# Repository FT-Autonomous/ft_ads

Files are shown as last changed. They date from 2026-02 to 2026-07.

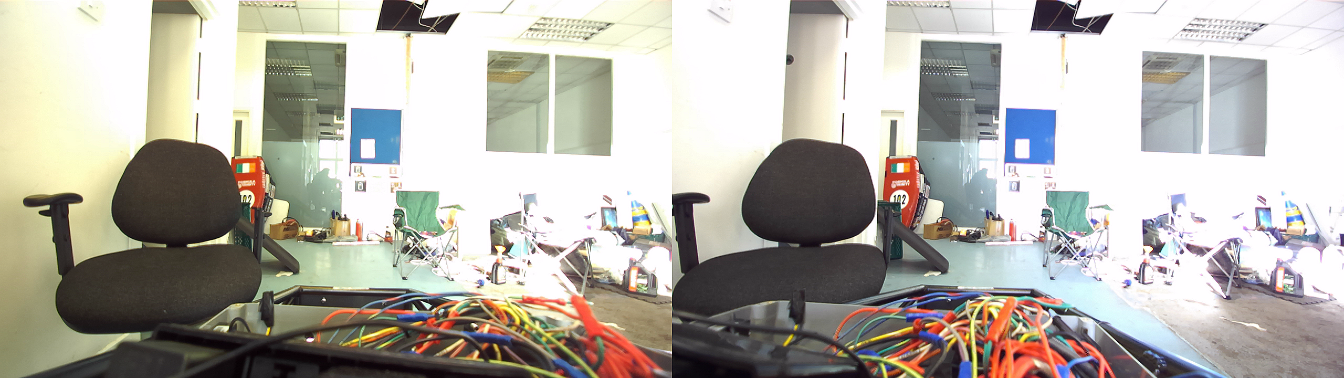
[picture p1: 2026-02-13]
Mounting System CAD/Useful Resources/Zed2i Reference Images/Explorer_HD720_SN38337619_14-20-30.png

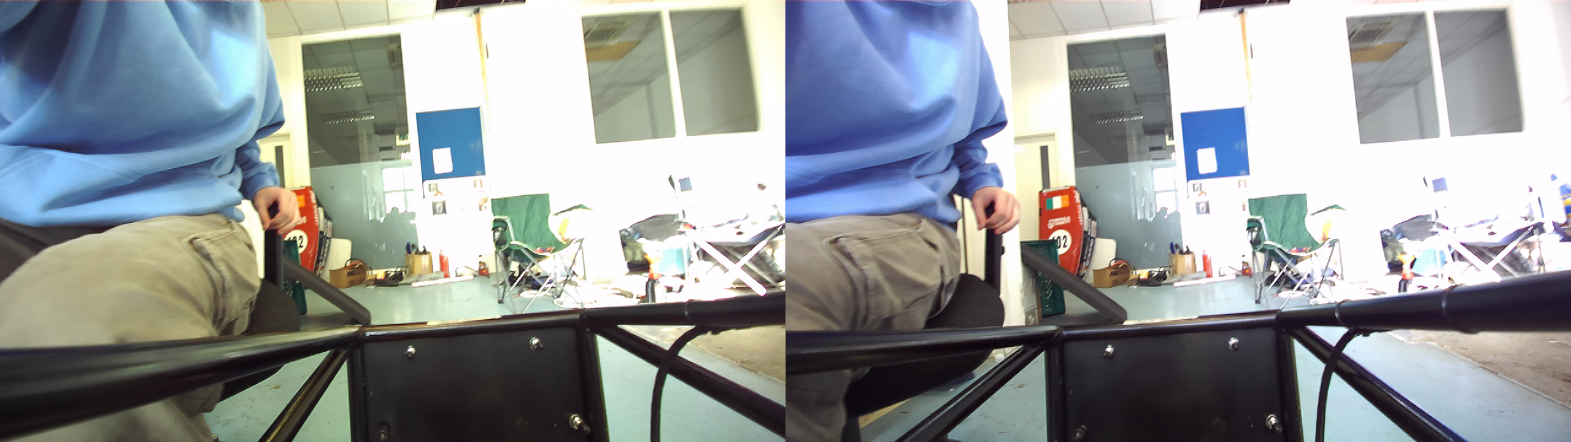
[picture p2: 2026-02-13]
Mounting System CAD/Useful Resources/Zed2i Reference Images/Explorer_HD720_SN38337619_14-18-11.png

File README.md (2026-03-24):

# ft_ads

## About
ADS gang type shit

## Directory Structure

### Mounting System CAD
all the CAD files as related to the mounting of sensors and compute devices - managed by [moranC1018](https://github.com/moranC1018) and [reubxn](https://github.com/reubxn)

### compute flow
scripts and diagrams that describe how data goes from the sensor stack, down to the microcontrollers, and back up - managed by [J-Carrig](https://github.com/J-Carrig)

### kiCad
all electrical/wiring diagrams in KiCad - managed by [gitdamp](https://github.com/gitdamp) and [J-Carrig](https://github.com/J-Carrig)

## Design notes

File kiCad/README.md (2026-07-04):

Hello, ADS person. This is the KiCad folder where we make our circuit schematics. You may be wondering why there are two different folders, one called "ads_circuit_schematic" and one called "fsuk-ads-electrical". That is a good question. Both of them were made by me (Jack), both of them are attempting to do the same thing (documenting and designing the ADS circuit schematic), but one of them is really not great and isn't very clear. The fsuk one is the newer and more complete one. There will be another file explaining each of the sections in that schematic and what they are for. Thank you for reading.

If you have any questions, please email jbradsha@tcd.ie or message me on Slack (Jack Bradshaw) :)

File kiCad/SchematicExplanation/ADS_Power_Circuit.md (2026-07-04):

The ADS power circuit's main function is to supply power to all sensors, actuators and computers used to allow the car to complete its Autonomous missions.

You will note that the power circuit does not have any of these sensors or computers on it. This is because they would only serve to clutter the schematic and are not necessary for the illustration of power. Instead there are power symbols that show which item the current is going to. There is a separate sheet that's purpose is to document the actuator and motor powering, see "Actuator_drive" and the one that documents the sensors and compute is called "Compute_sensors". Both of these will have  power symbols corresponding to what is in the power circuit to show where they get their power.

The ADS power circuit consists of two main sub circuits: 1. That which is gated by the SW80 contactor 2. That which is not. This stems from the rule T14.5.5 stating "when the ASMS is in the 'off' position, among the conditions that must be fulfilled, the sensors and the processing units can stay operational". Therefore, the compute and sensors are not gated by the SW80 contactor. The SW80 contactor, is a normally open relay contact, that is energised by a coil gated by the LVMS/ASMS path in the SDC circuit and thus does not allow current to flow to things downstream of it when the ASMS is in the 'off' position. 

The compute side of things is also gated by another relay contact, with the coil that energises it once again lying in the SDC. However, this coil is energised on two conditions:1.The LVMS is on and 2. The  manual switch (green LED switch on the car) is on too. This way the compute module can be turned off either by the LVMS (required) or a manual toggle (not required but nice to have). Any special connections (e.g barrel jack, or usb) to supply power to the various items should be noted in text in the schematic. The jetson and pi should both have them at the time of writing this document.

The actuator side of things involves the linear actuators and the steering and braking motors. One will note there is a 12->24V converter in that subcircuit as both the steering and breaking motors require 24V. This means one should be carefule when sizing fuses for the input side of the converter as current on the input side will be much greater than the current drawn on the output side. Power in = power out and voltage is fixed. For example, if we have 30 A of current drawn on the output side, 12x = 24V*30A, x = 60 A, and that is without regard for the converter not being 100% efficient. Currently fuses have not been tested for either of the steering or braking motors and so that still needs to be done, starting low of course and working our way up as fuses blow. This document should be changed to omit the previous sentence should testing be done and a fuse sizes chosen :)

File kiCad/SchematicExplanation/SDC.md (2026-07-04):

The Shutdown Circuit's (SDC) main job is to, in the event of something going wrong, shut down the cars tractive system (TS). Essentially it must turn the car off. Since it is based off the old IC circuit, it also serves as the electronic control (ECU) for the car and so any electrical components can be shutoff by turning the LVMS isolator to the off position.

This is acheived through a series of switches, buttons and relays, pretty much all in series, so that if anything is tripped, power ceases to energise certain relays that cause the engine etc to shut off. This is the spine of the circuit. There are many switches in here, look at the rules for things like BOTS, BSPD, the shutdown buttons and the inertia switch. There are some additions strictly added for ADS that I will examine further here. 

1. The Remote Emergency Stop:
The RES is essentially a transmitter and receiver combination. The receiver energises a normally open relay contact when receiving a signal and this causes the spine to stay powered and so the car keeps running. If, for a plethora of reasons, the signal stops being transmitted (too far away, obstruction, purposeful cessation etc.) the RES opens the spine. T14.3.5 states that the RES may be bypassed when in manual driving mode (it is only there to stop the autonomous car) and so a bypass exists through use of a forcibly guided, normally closed relay contact, with its coil energised by the ASMS. If the ASMS is switched on, the RES is no longer bypassed and therefore can cause the car to stop. A secondary role of the RES is that it must be the thing that sends the 'Go' signal to the car in order to make it start driving in Autonomous mode and this can be done over CAN or some weird latching K2 thingy in its datasheet (not a fan of the second option tbh).

2. The Emergency Braking System (EBS):
The EBS is part of the Autonomous System Brake (ASB) and if the SDC spine is tripped, it must activate within 200 ms, braking with a decelleration of at least 10 m s^-2. To accomplish this, the coil that energises the normally open relay that supplies power to the EBS will be in paralell to the relays that disable the tractive system, so that they both happen due to the same event. At the time of writing this document, this has not been designed but totally should be.

3. The 12->24V Converter:
This converter is after the ASMS and is just there because both the SISF2 (forcibly guided relay that allows the bypass of the RES) and the SW80 coils both require 24 volts. If this ever changes then it can be removed of course.

4. The Autonomous System Relay in series with the RES:
This is a relay that is controlled by the computer (Jetson). As per the rules, it is allowed to close this normally open contact if it thinks everything is all good (check rules for actual wording). The power supply for the coil that implements this must then be controlled by the computer (perhaps MOSFET controlled by ESP32 receiving heartbeat from watchdog routine) but at the time of writing this document has not been implemented. Ask Joel Jojan (goat) for updates on this if he is still with us.

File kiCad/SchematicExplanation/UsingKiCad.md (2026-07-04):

This file will just be for explaining what I have learnt in my short time using KiCad, that may help if it is your first time. I will try and give a list of things that are good to know when editing the schematics and some shortcuts etc.

1. Netclasses:
One of the more useful features of KiCad is netclasses. This is essentially a way of saying "Anything with this name is part of this net". This is useful for two reasons. The first is that anything with an exact net name will be electrically connected (useful for global power symbols such as the ones that go between the ADS power circuit and the compute and actuator drive circuits). The second is a little bit more of an aesthetic reason. It is possible to assign a netclass a wire thickness, color, type and then possible to assign any name to that netclass. For example I can create the netclass "SDC_SPINE", make its wire thickness 0.3 mm, its colour dark red, and its linetype solid. I then can create a netclass assignment with the pattern "SDC_SPINE*" and anything with that label or connected to a net starting with that string, will become that colour, thickness and linetype.

2. Symbol Editing:
It is useful to know that a single symbol can have multiple components that can be spread out across a schematic (amount of units). That the convention for pin spacing on a symbol is 100 mm. That the grid size when editing symbols (and in general) can be adjusted for more accurate drawing of the symbol. That new symbols can be made using parts or all of old ones. That pin names do not have to be shown, and if they are that they do not have to be shown inside the symbol body. That there is a pre-existing library called "FSUK_ADS" that symbols should be taken out of and added into. This will be in the files and have the termination ".sym".

3. Shortcuts:
A - Add a symbol
T - Add text
G - If pressed after selecting a component, will move the component without breaking the wired connections
M - Will move the component, disregarding the wired connections
P - Place power symbols
W - Use the wire tool
Q - Add a no connect symbol
L - Label something
S - Draw a hierarchical sheet

Creating a box by clicking and dragging with your mouse - If you drag from top left to bottom right, it only selects things completely enclosed in the box. If you drag from bottom right to top left, it selects everything even touched by the box.

There are way more but you will just figure them out as you go. For people in future who used this file to help them learn, please update it as you go along in order to help future people :)

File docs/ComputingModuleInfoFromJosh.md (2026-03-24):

As seen in the computing flow chart in this folder the esp32's need to be powered off a usb hub as there are not enough ports on the Pi. This means that they will be communicating over serial (indicated in blue) to the Pi. 

The USB hub allegedly needs 5V at 500 mA and this gets it from the Pi, which is on 5V and max 3A

There are four things that need to be communicated with over Ethernet:

 - Steering Motor Driver
 - Jetson - power rating of 60 W
 - Pi
 - LiDAR

The rest of the modules just need an esp-32 to control everything and these will communicate with the Pi through serial.

The ASMS switch is going to be connected to the Jetson with a USB and that is all that we know for now.

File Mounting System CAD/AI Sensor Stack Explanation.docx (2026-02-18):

Components:

- LiDAR
- Zed2i (camera)
- Nvidia Jetson
- Modem
- LiDAR box
- GPS thingy
- A lot of wiring

What actually has a required location:

- LiDAR
- Zed2i

Other physical restraints:

The LiDAR physically cannot be separated from the LiDAR box.

We need minimal movement of AI components (e.g. keep everything together except the stuff that has to move. For ADS, AI (Hardware) will make these components convenient by design, all taking a small (less than 20cm^3 footprint).

Ideally, the LiDAR and Zed2i should be kept as closely together as possible – testing is currently being done to determine the furthest safe distance (specifically on height and depth). Zed2i should be vertically higher than LiDAR. Both should be on the same horizontal plane within the car (wheel-to-wheel plane on car). Depth difference is the current unknown variable currently being tested, it has never been more than 10cm apart on AI car.

Not relevant for placement, but in manufacturing remember that these components run hot, hot enough to make PLA 3d prints deform if under any pressure.

{add in drawing for visualisation}

LiDAR Placement Requirements:

- Ideally should be as far forward on the car as possible.
- Needs to remain level.
- Should be as low to floor as possible while retaining a full 180-degree view in front of it.
- Very expensive and on loan from another company, so need to keep it safe (can’t be on front of the car if there’s a crash, because then FT is in debt).
- For mounting remember that there needs to be a direct line for fast wiring between it and the LiDAR box (space can’t just be left to run wire, the LiDAR will have to fit through gaps as well, maybe hatch somewhere?).
- Requires minimal vibrations to work well.

Current idea for LiDAR placement:

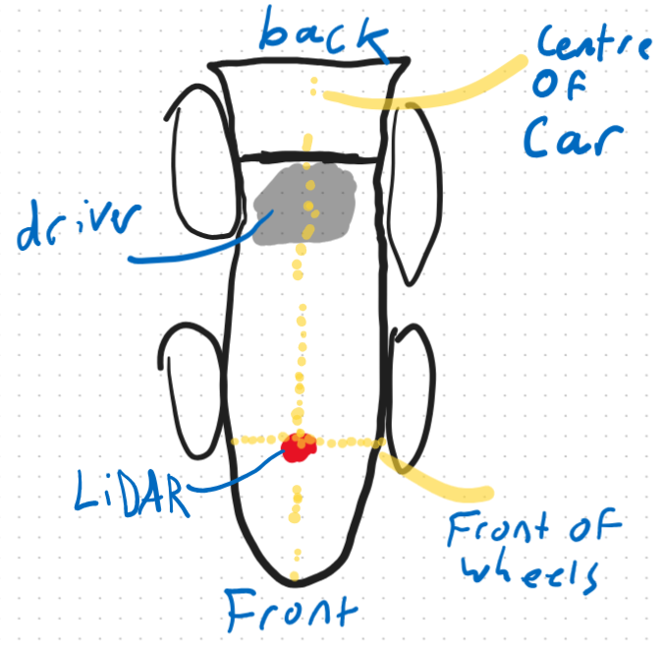
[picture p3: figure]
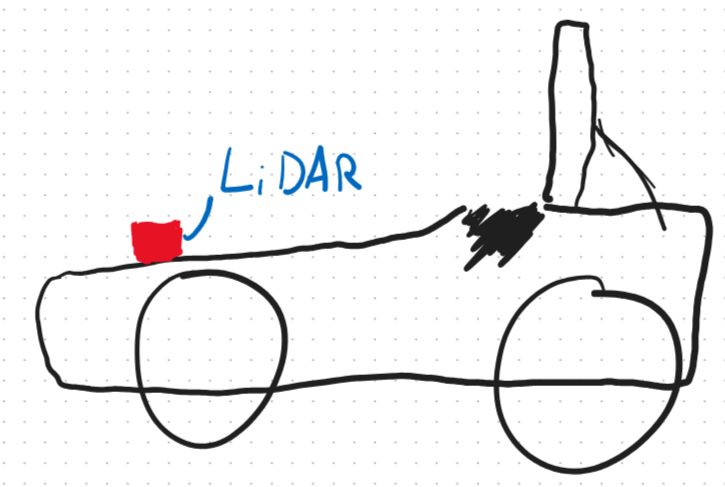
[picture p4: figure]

Zed2i Placement Requirements:

- Needs as clear a view of the road as possible – meaning a placement as high as possible (above driver?).
- Needs to remain level.
- Bolted USB-C cable used to plug in, no restraint on placement based on cabling but we would have to buy a dedicated ADS cable for it depending on placement (not issue, just to remember for assembly).
- Requires minimal vibrations to work well.

Note: Perfect camera placement should be akin to a driver’s vision while they are driving – but we cannot block the driver’s line of sight at all.

Current idea for Zed2i Placement:

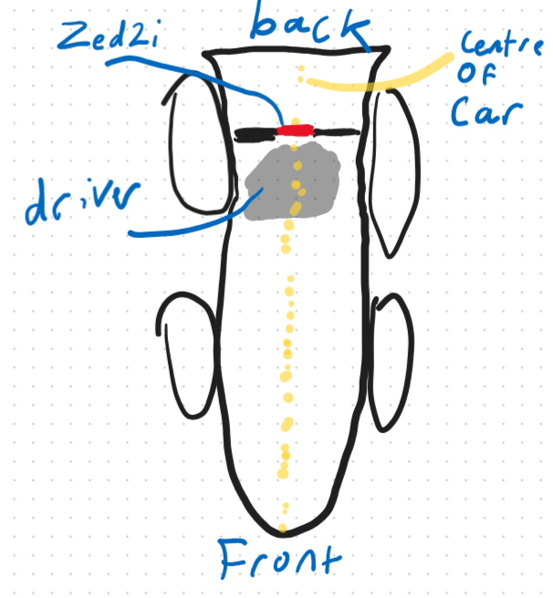
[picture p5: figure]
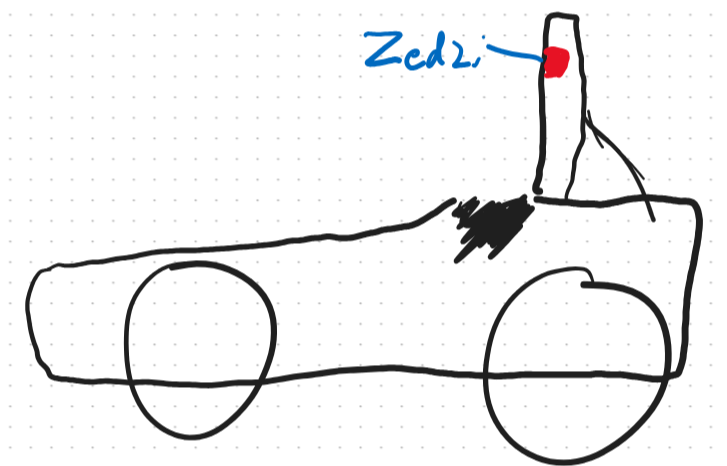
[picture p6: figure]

The rest of the AI mount must fit in the car somewhere. Only real requirements are:

- Ventilation
- Waterproofing
- Easy to access for removal/placement.

From a software perspective, we have 0 preference on placement. It’s entirely on where on the car it will fit.

Guide to AI Sensors ADSI 28/01/2026

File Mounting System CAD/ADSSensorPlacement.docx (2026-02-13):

ADS AI Sensor Placement Decisions and Rational

LiDAR Placement Requirements:

- Ideally should be as far forward on the car as possible.
- Needs to remain level.
- Should be as low to floor as possible while retaining a full 180-degree view in front of it.
- Very expensive and on loan from another company, so need to keep it safe (can’t be on front of the car if there’s a crash, because then FT is in debt).
- For mounting remember that there needs to be a direct line for fast wiring between it and the LiDAR box (space can’t just be left to run wire, the LiDAR will have to fit through gaps as well, maybe hatch somewhere?).
- Requires minimal vibrations to work well.

Zed2i Placement Requirements:

- Needs as clear a view of the road as possible – meaning a placement as high as possible (above driver?).
- Needs to remain level.
- Bolted USB-C cable used to plug in, no restraint on placement based on cabling but we would have to buy a dedicated ADS cable for it depending on placement (not issue, just to remember for assembly).
- Requires minimal vibrations to work well.

Note: Perfect camera placement should be akin to a driver’s vision while they are driving – but we cannot block the driver’s line of sight at all.

AI Computer Mount (Lunchy) Placement Requirements:

- Wiring can reach camera and LiDAR safely.
- Enough space surrounding mount for adequate airflow to/from components.
- Easy to access/remove for transport between AI-ADS and AI-DDT cars.
- Won’t become a projectile in the event of a crash.

Rough Illustrations of Car AI Sensor Placements

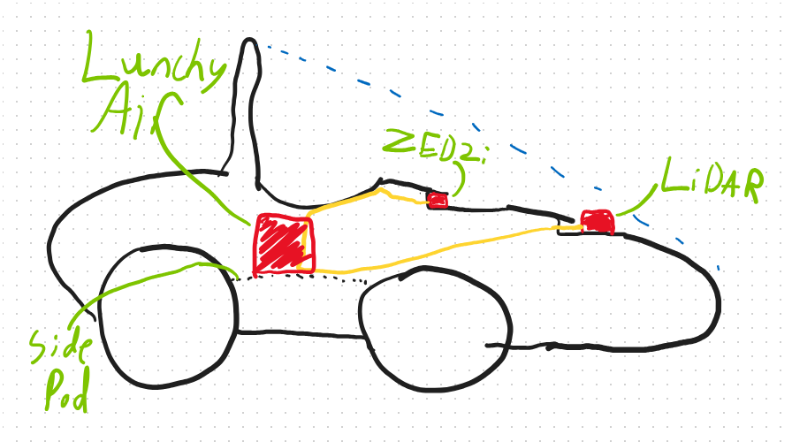
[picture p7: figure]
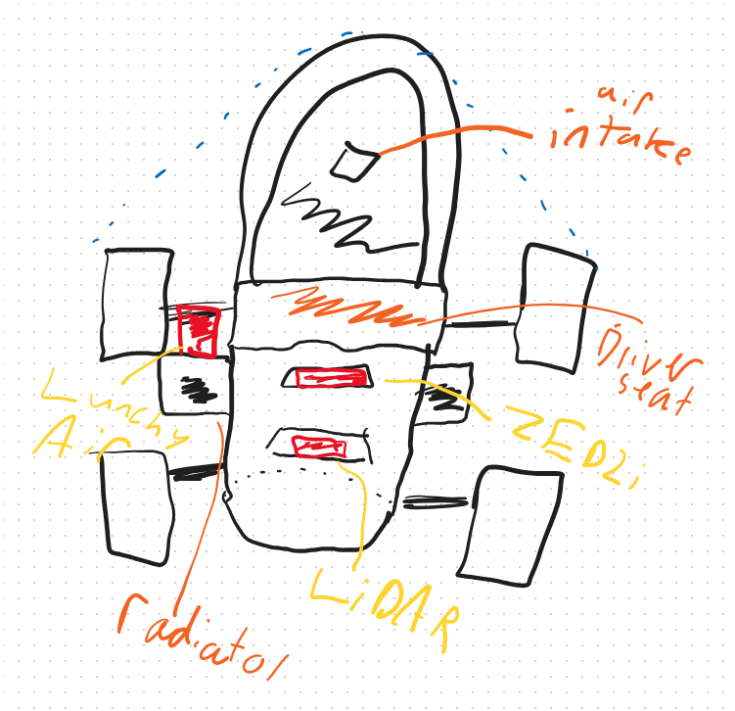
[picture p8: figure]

CAD View of Nosecone Car Loose AI Sensor Placements

(mm locations have yet to be made, will be done after discussion with Aerodynamics and electronics)

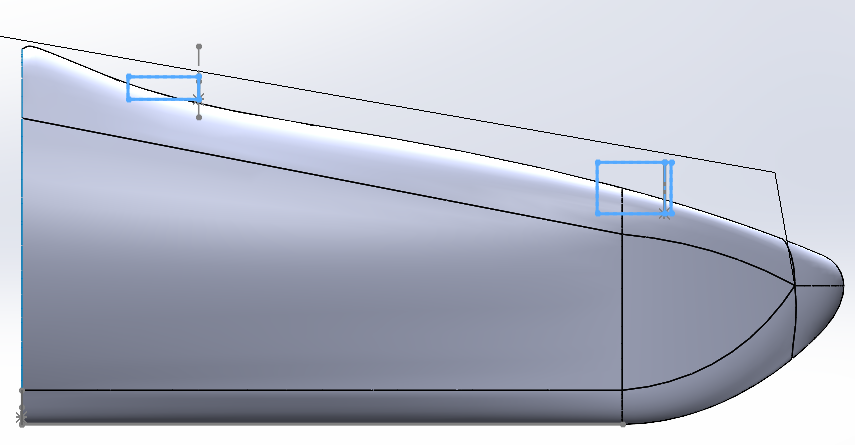
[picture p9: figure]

The uppermost line is the required Line of Sight of the driver

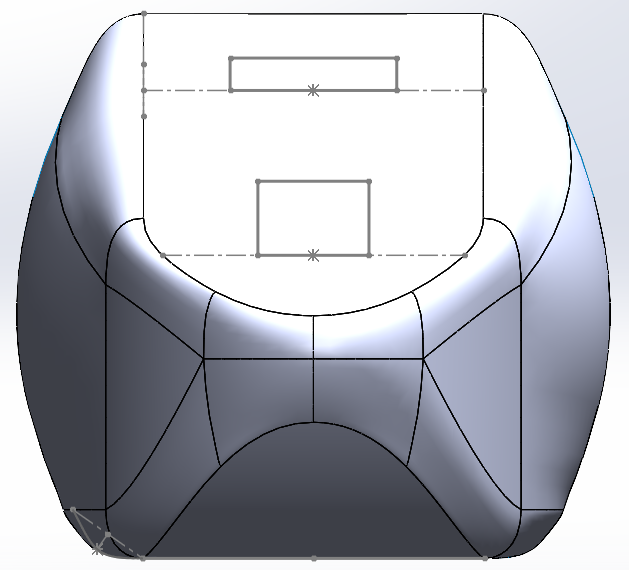
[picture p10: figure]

Rational:

The location for the LiDAR remains lower than and in front of the Zed2i to allow proper functioning of the AI stack. The LiDAR and Zed2i will both remain level to the ground in the design process. Mounting plates will be created that will have the nosecone overhang them and can be easily slid out for disconnecting the LiDAR when needed, allowing for waterproofing of the internal car body and removal of the LiDAR.

All components remain covered by the roll-hoop-to-chassis safety areas where they should not be damaged in the event of a crash.

Lunchy is placed on top of the left sidepod of the car when looking at it from the nosecone. This is mounted above the radiator with about 10cm between the top of the radiator and top of the nosecone, meaning heat should be mostly dissipated before reaching Lunchy. An aerodynamic box will be created (Lunchy Air) to cover the components, attempting to minimize aerodynamic impact of the box placement while also meeting waterproofing requirements. Placement of air vents will be required, as well as a cut in the carbon-fibre body of the car to feed cabling out of Lunchy Air and to the sensors and other components of the ADS car.

The choice to indent the sensors into the car as opposed to extrude them was done to meet the requirements of maintaining the driver’s line-of-sight, which would be an instant scrutiny fail if blocked. It also can mean an easier incorporation of a sunshade for the Zed2i while keeping both sensors level to the ground.

For the LiDAR, the only placement options feasible were along the nosecone – this location was chosen as it was as close to the front of the chassis as possible, and thus as low to the ground as possible, while remaining within the Surface Envelope defined by the FS-AI rules (between top of roll-hoop to end of chassis frame).

The Zed2i could have been placed anywhere along the same horizontal axis as the LiDAR, but making it higher gave better clearance and vision of the ground. It was not placed just under the roll-hoop due to the placement of the intake for the engine, which we were told should not be blocked. It is also untested if the distance between the Zed2i and LiDAR would cause parallax or other syncing issues between the sensors. For this reason, we chose to place it as high on the nosecone as possible. There was a box containing the electronics for the rest of the car sitting near the top of the chassis, so that box will be modified to have the front of it house the Zed2i, giving it a clean path to the rest of the car and a strong mount.

For mounting and dismounting, it could be useful to buy a second cable for the Zed2i which can be permanently kept on the ADS car, assuming budget allowed for it. It is not strictly necessary but would make mounting and dismounting in between cars faster. It would cost {price} to buy this cable. The AI car does not require a cable length greater than 40cm and our existing cable works on the ADS car, so cable length is not a constraint in buying a new cable.

ADS Car AI Sensor Mount Formula Trinity

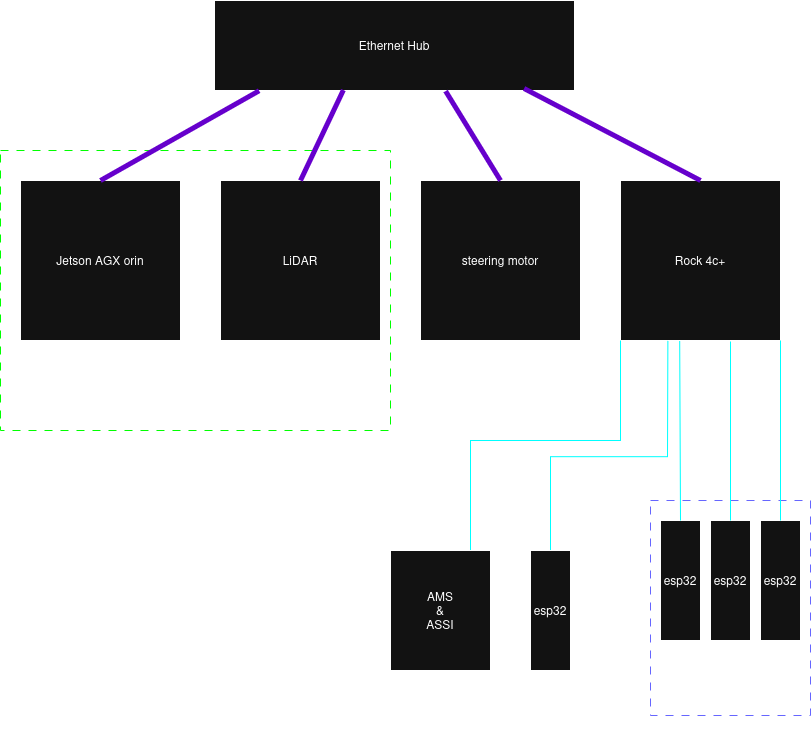
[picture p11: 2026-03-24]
docs/compute flow/compute_flow_diagram.png

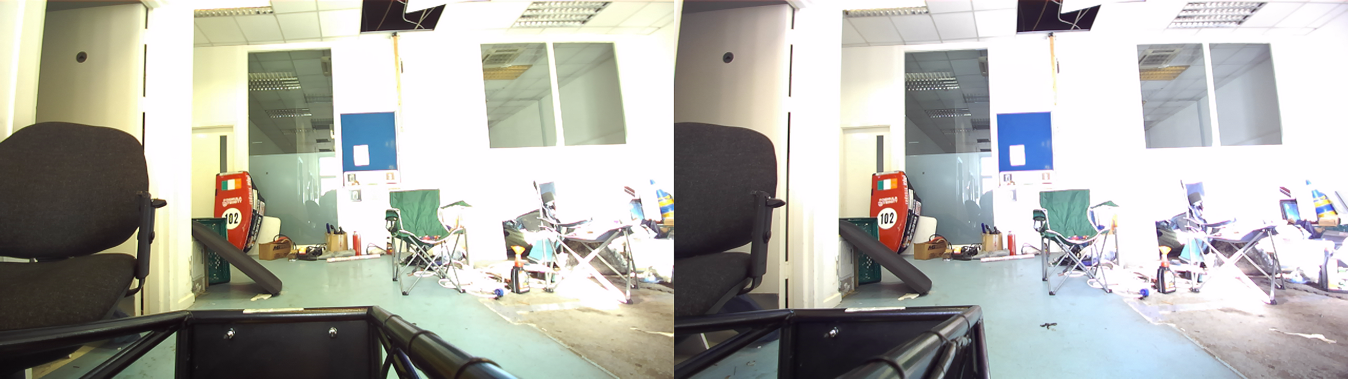
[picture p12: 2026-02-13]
Mounting System CAD/Useful Resources/Zed2i Reference Images/Explorer_HD720_SN38337619_14-21-49.png

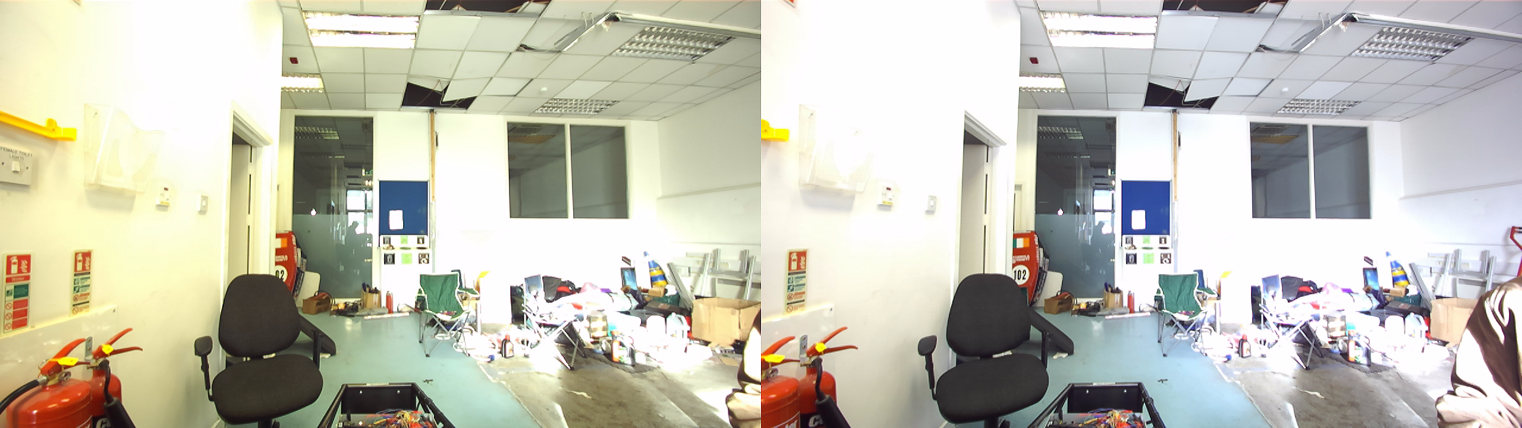
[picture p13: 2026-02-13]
Mounting System CAD/Useful Resources/Zed2i Reference Images/Explorer_HD720_SN38337619_14-19-13.png

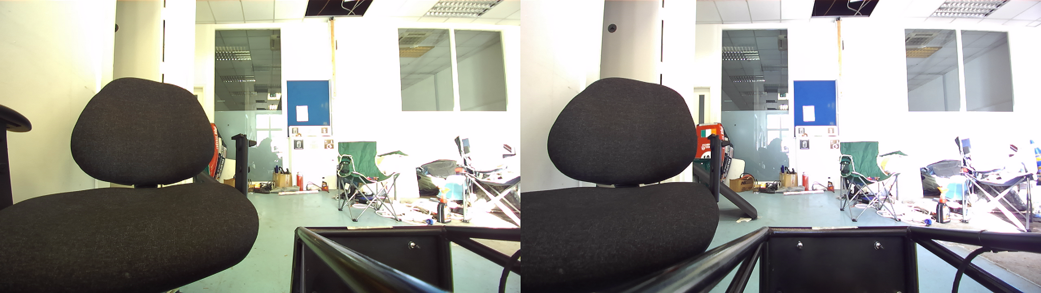
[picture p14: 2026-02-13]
Mounting System CAD/Useful Resources/Zed2i Reference Images/Explorer_HD720_SN38337619_14-21-28.png

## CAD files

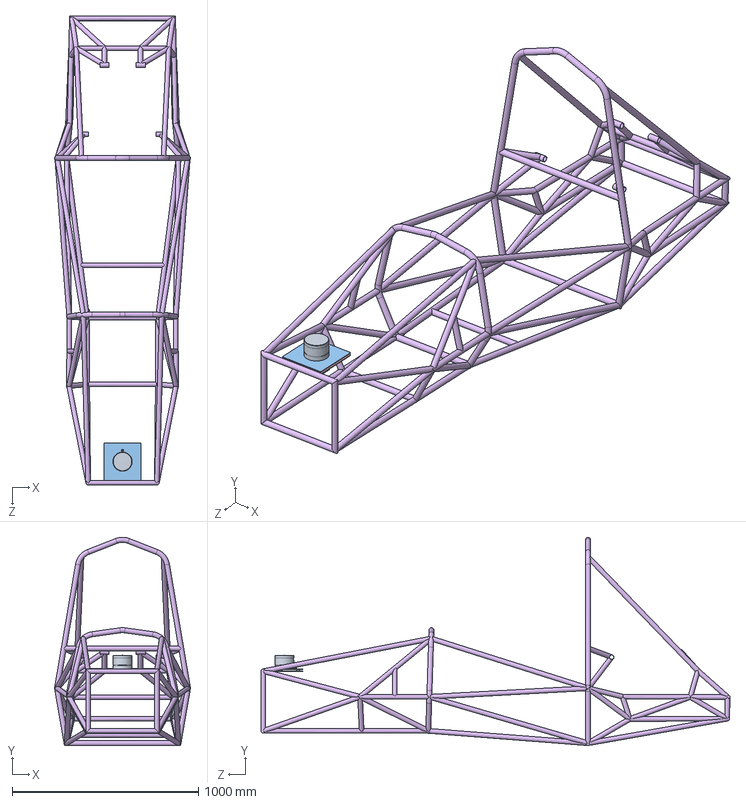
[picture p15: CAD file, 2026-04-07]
Complete_Sensor_Assembly_Nosecone_and_Chassis.SLDASM
730.4 x 1117.8 x 2515.0 mm
Full-Chassis-Design
Lidar_Lower_Plate
19.05mmHemisphere_Sorbothane x 4
Baseplate 3.0
FrontBar_40x60x3 x 2
LiDAR

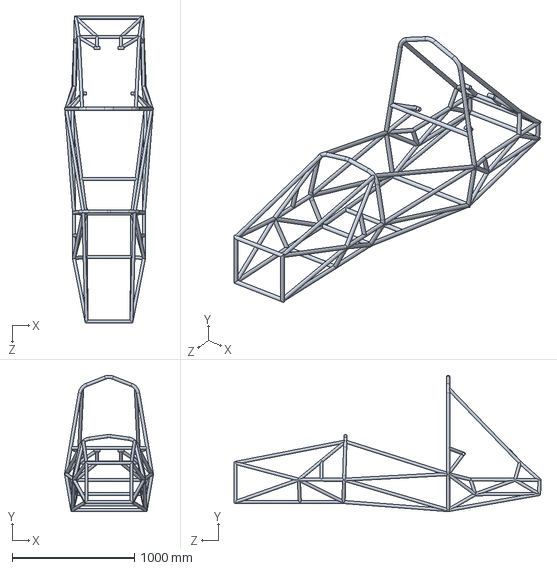
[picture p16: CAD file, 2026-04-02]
Mounting System CAD/Full-Chassis-Design.SLDPRT
730.4 x 1117.8 x 2515.0 mm

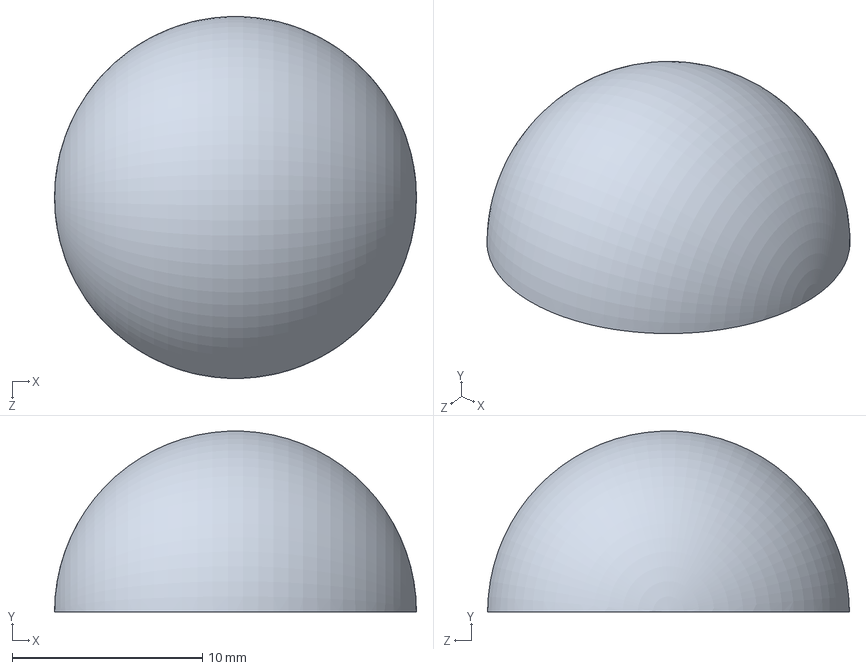
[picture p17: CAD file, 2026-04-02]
Mounting System CAD/Chassis Addition Parts/19.05mmHemisphere_Sorbothane.SLDPRT
19.1 x 9.51 x 19.1 mm

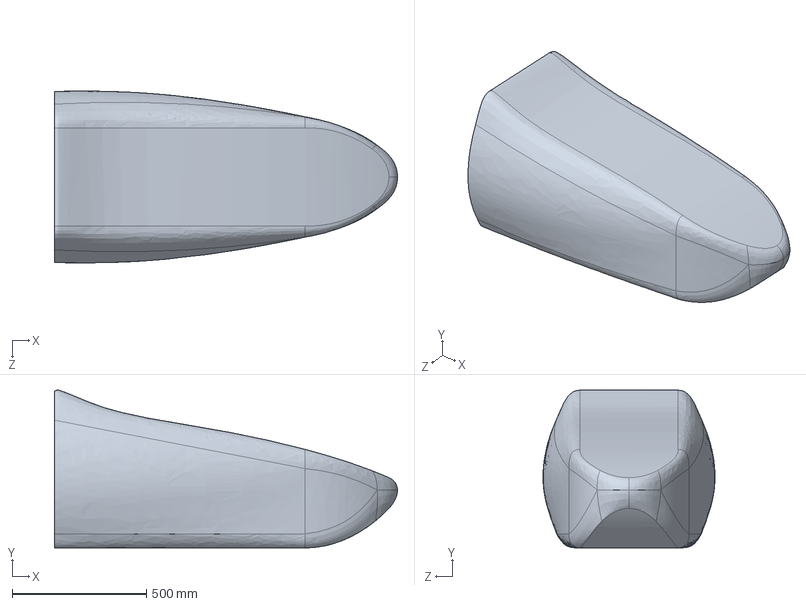
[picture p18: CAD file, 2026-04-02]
Mounting System CAD/FTX6_Nosecone_with_Rough_Sensor_Placements.STEP
1278.8 x 588.2 x 641.2 mm

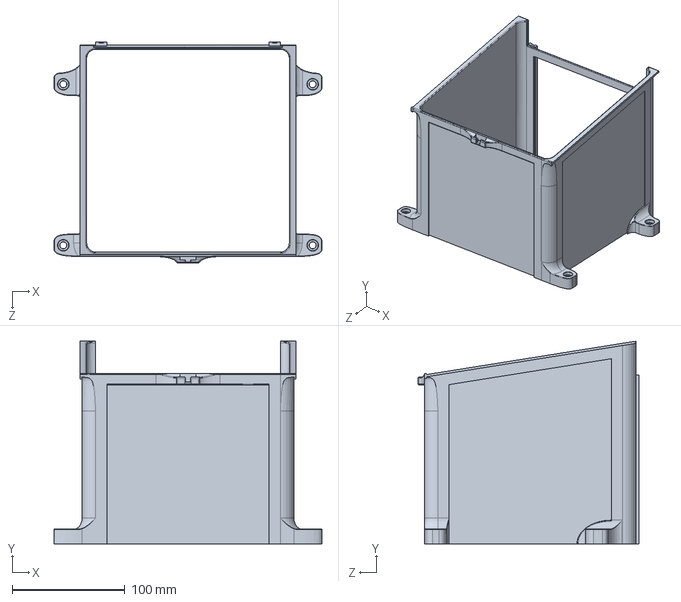
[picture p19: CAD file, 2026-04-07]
Mounting System CAD/Lunchy Airy/Body Lunchy.SLDPRT
238.0 x 179.9 x 196.2 mm

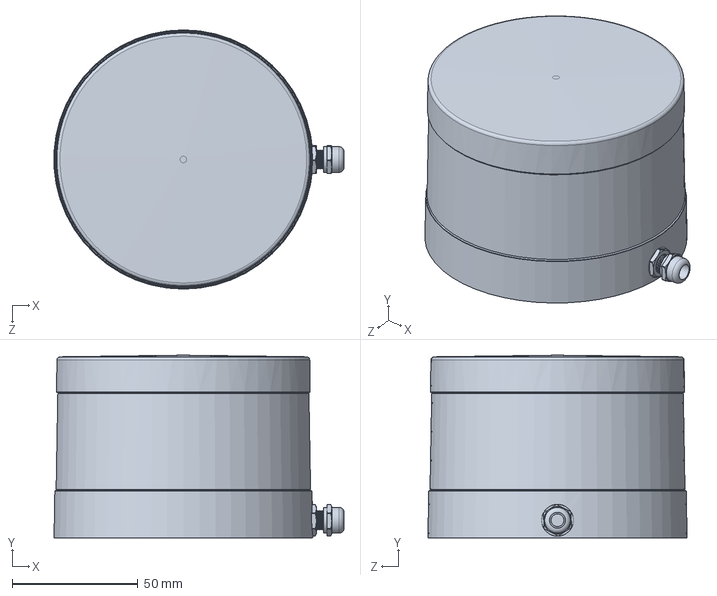
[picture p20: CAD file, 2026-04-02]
Mounting System CAD/What Needs To Fit/LiDAR.SLDPRT
115.5 x 72.7 x 103.3 mm

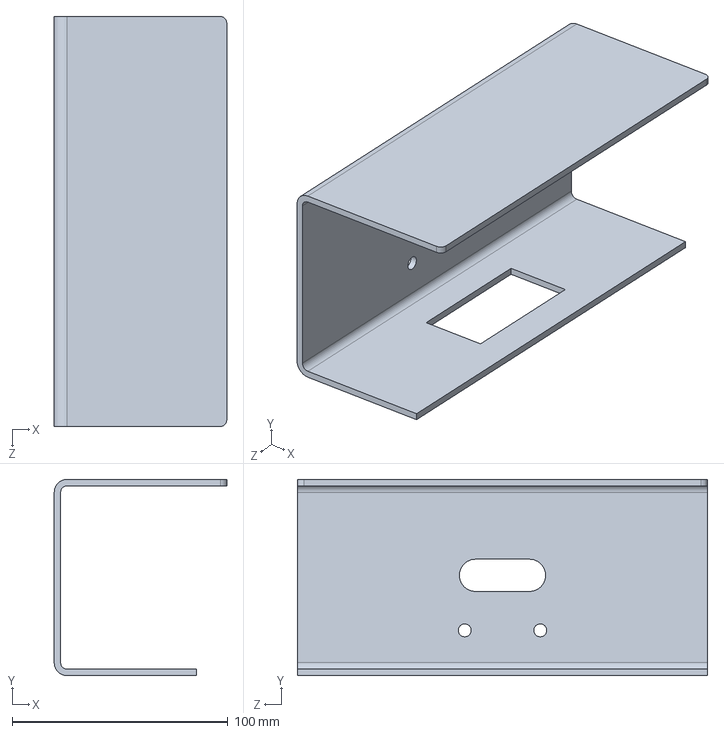
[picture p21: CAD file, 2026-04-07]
Mounting System CAD/ZED2i mount/Camera_mount.SLDPRT
80.0 x 91.0 x 190.0 mm

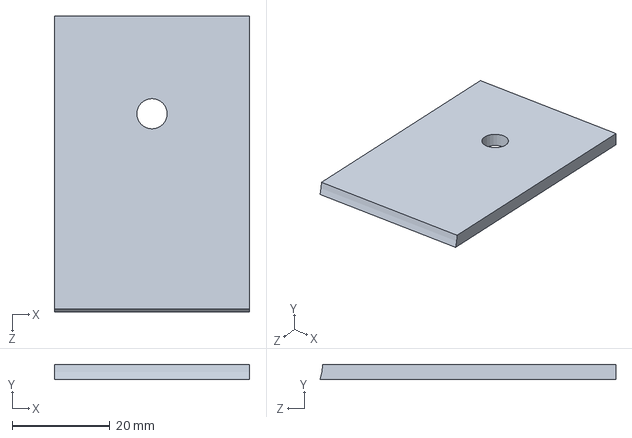
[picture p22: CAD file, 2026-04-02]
Mounting System CAD/Chassis Addition Parts/FrontBar_40x60x3.SLDPRT
40.0 x 3.00 x 60.6 mm

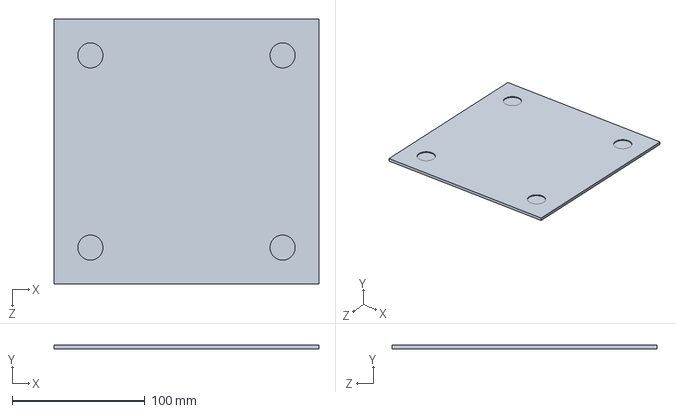
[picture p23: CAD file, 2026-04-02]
Mounting System CAD/Lidar_Lower_Plate.SLDPRT
200.0 x 3.00 x 200.0 mm

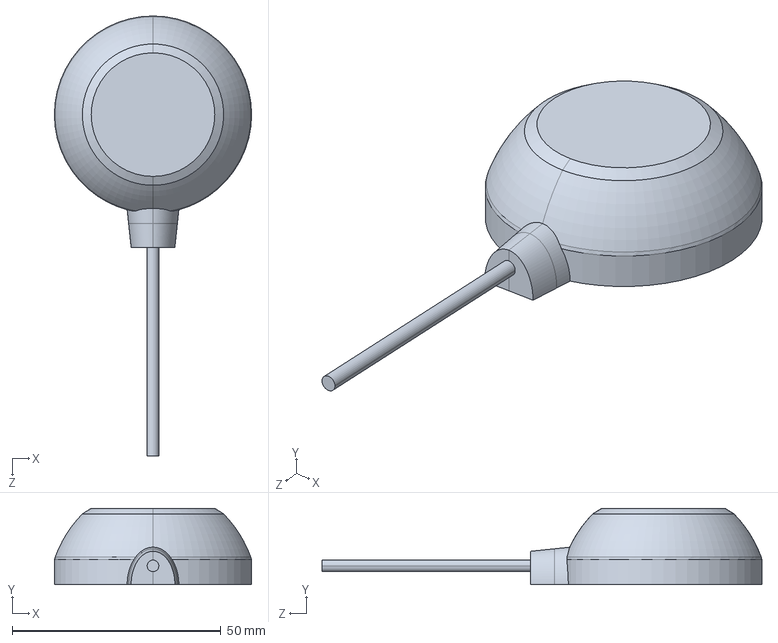
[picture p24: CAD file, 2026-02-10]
Mounting System CAD/What Needs To Fit/ANT-GNSS-RTK-TALLYSMAN-TW8889.SLDPRT
47.3 x 18.3 x 105.5 mm

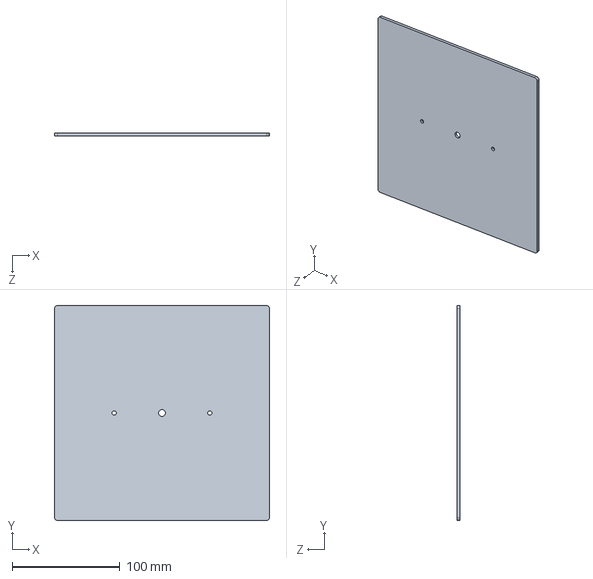
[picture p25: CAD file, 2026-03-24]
Baseplate 3.0.SLDPRT
200.0 x 200.0 x 3.00 mm

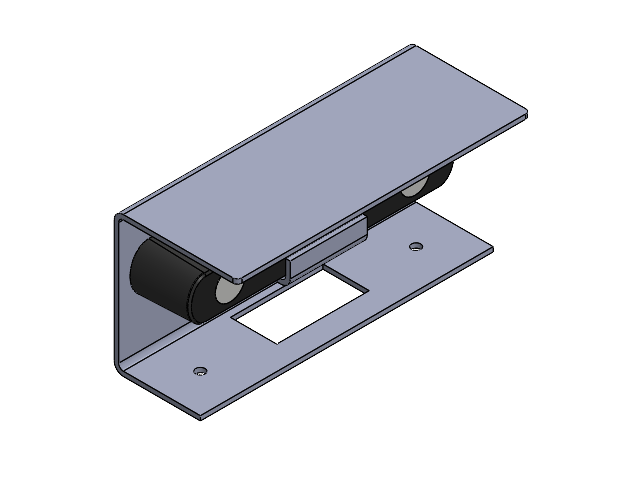
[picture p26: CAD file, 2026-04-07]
Mounting System CAD/ZED2i mount/ZED2i_Mount_assem.SLDASM
Camera_mount
optic.step x 2
ZED2_IP_Outer_with_lens.step
ZED2_IP_Outer_with_lens-0.step
ZED2_IP_Outer_with_lens-1.step
Mount_L_bracket

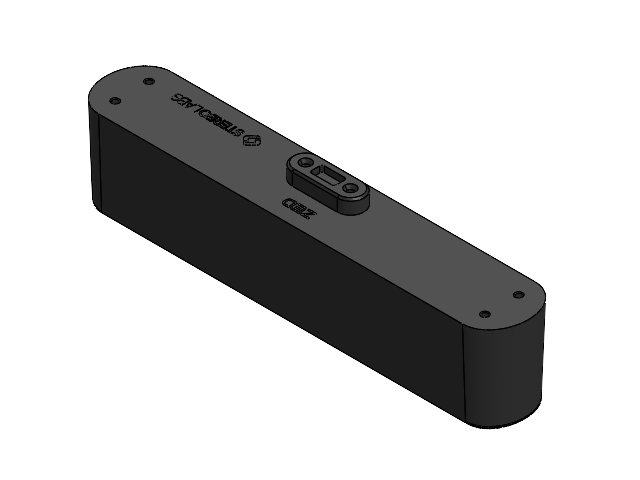
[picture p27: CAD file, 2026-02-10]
Mounting System CAD/ZED2i mount/ZED2i.SLDASM
optic.step x 2
ZED2_IP_Outer_with_lens.step
ZED2_IP_Outer_with_lens-0.step
ZED2_IP_Outer_with_lens-1.step

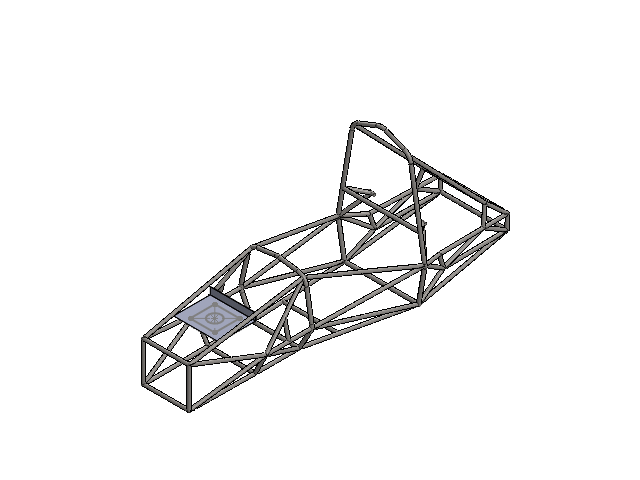
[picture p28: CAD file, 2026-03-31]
Mounting System CAD/mount roughly on chassis.SLDASM
basebasebaseplate
Straight up chassis Chassis TON 20.05

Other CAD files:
Mounting System CAD/Complete_Sensor_Assembly_Nosecone_and_Chassis.SLDASM
Mounting System CAD/Sensor_Chassis_Additions.SLDASM
Mounting System CAD/lidar and cone.SLDASM
Guillotine.SLDPRT
Mounting System CAD/Baseplate updated.SLDPRT
Mounting System CAD/Baseplate.SLDPRT
Mounting System CAD/Chassis Addition Parts/FrontLongBar_40x40x3Thin+InclinedSection.SLDPRT
Mounting System CAD/Chassis Parts.SLDPRT
Mounting System CAD/FTX6_Nosecone_with_Rough_Sensor_Placements.SLDPRT
Mounting System CAD/What Needs To Fit/Lidar Box.SLDPRT
Mounting System CAD/ZED2i mount/Mount_L_bracket.SLDPRT
Mounting System CAD/basebasebaseplate.SLDPRT
Mounting System CAD/camera mount.SLDPRT
Mounting System CAD/mount.SLDPRT

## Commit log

2026-02-10 folder to store kiCad files for the wiring diagramm
2026-02-10 New folder for mounting sensor solution
    [ANT-GNSS-RTK-TALLYSMAN-TW8889.SLDPRT, LiDAR.SLDPRT, Lidar Box.SLDPRT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]
2026-02-10 Initial KiCad schematics
    [12-24_step.kicad_sch, Computing_Module.kicad_sch, ads_circuit_schematic.kicad_pcb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]
2026-02-13 Adding Zed Reference Images and Sensor Mounting Explanation documents
2026-02-13 Added FTX6 Nosecone model with reference Sensor locations (approximate)
    [FTX6_Nosecone_with_Rough_Sensor_Placements.SLDPRT]
2026-02-18 Added visual angle requirements to nosecone model
    [FTX6_Nosecone_with_Rough_Sensor_Placements.SLDPRT]
2026-02-19 Add files via upload
    rough placement of lidar
    [lidar and cone.SLDASM]
2026-02-24 Added camera mount
    [camera mount.SLDPRT]
2026-02-26 Added new symbols for linear actuators, added fuses, added 5V step down
    [5V_stepdown.kicad_sch, Computing_Module.kicad_sch, ads_circuit_schematic.kicad_sch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]
2026-02-28 made a new symbol for the steering motor in the steering module
    [steering_module.kicad_sch]
2026-03-02 Added placeholder for steering motor driver
    [steering_module.kicad_sch]
2026-03-10 Rough baseplate
    [Baseplate.SLDPRT]
2026-03-10 Add files via upload
    Resized hole and added filleted edges
    [Baseplate.SLDPRT]
2026-03-11 added compute flow diagram (WIP)
2026-03-11 finished linear actuator wiring diagram
    [linear_actuator_module.kicad_sch]
2026-03-16 added breaking motor
    [braking_module.kicad_sch, linear_actuator_module.kicad_sch]
2026-03-18 updated actuator schematic
    [linear_actuator_module.kicad_sch]
2026-03-24 Add Festo VUVS solenoid valve KiCad symbol
2026-03-24 Updated vague documentation for the voltages and connection of the various modules and components
2026-03-24 Remove old solenoid symbol
2026-03-24 Added Liam's symbol for the braking motor driver
2026-03-31 Added the solenoid schematic
    [Solenoid_schematic.kicad_sch]
2026-04-01 Some changes to chassis and base-base plates for sensors added, will commit to main when these are done so I'm not spamming main
    [Chassis Parts.SLDPRT, FTX6_Nosecone_Editable.STL, FTX6_Nosecone_with_Rough_Sensor_Placements.SLDPRT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]
2026-04-02 working cuttable nosecone, accurate chassis CAD for LiDAR placement (pending final baseplate and guillotine confirmation), assembly connecting chassis and nosecone cad to sensors to view how car fits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
    [19.05mmHemisphere_Sorbothane.SLDPRT, Chassis Parts.SLDPRT, Complete_Sensor_Assembly_Nosecone_and_Chassis.SLDASM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]
2026-04-07 Added ZED2i Mount
    [Camera_mount.SLDPRT, Mount_L_bracket.SLDPRT, ZED2i.SLDASM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]
2026-04-07 Adding Lunchy air
    [Body Lunchy.SLDPRT]
2026-07-01 Initial project scaffolding for renewal
    [fsuk-ads-electrical.kicad_pcb, fsuk-ads-electrical.kicad_sch]
2026-07-01 Setup netclasses for power and comms and added power symbols
2026-07-02 Added main power spine for ADS power circuit
    [SDC.kicad_sch, actuator_drive.kicad_sch, ads_power_circuit.kicad_sch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]
2026-07-02 Created DC-DC voltage converter symbol
2026-07-02 Created panasonic automotive relay coil and SPDT contactor that gates compute
2026-07-02 Updated appearance of relays
2026-07-02 Added more power symbols and worked on wiring for power circuit
2026-07-02 Added power symbols for motor and steering and wired up with fuses
2026-07-02 Finalised first draft of ADS power spine with all fuses and converters. Some fuses still need validation!
    [ads_power_circuit.kicad_sch]
2026-07-02 Designed SISF2 and edited relay symbols to have pin names on outside
    [ads_power_circuit.kicad_sch]
2026-07-02 Added SISF2 relay symbol and some others such as ASMS, LVMS and shutdown buttons
2026-07-03 Added symbol for MKS relay, used for latch and AS contacts
2026-07-03 Started constructing SDC spine and added RES symbol with intentional decision to have NO contact as a separate element in power spine and logic and control in other module
2026-07-04 Built most of SDC, apart from EBS stuff and engine shutdown relays. Realised latchcircuit is only for EV's (fuck I wasted so much time)
2026-07-04 Had not saved changes, this commit is for the last one :)
    [SDC.kicad_sch, ads_power_circuit.kicad_sch]
2026-07-04 Ignore KiCad autosave and lock files
2026-07-04 Added documentation to try describe some things
    [ads_power_circuit.kicad_sch]
